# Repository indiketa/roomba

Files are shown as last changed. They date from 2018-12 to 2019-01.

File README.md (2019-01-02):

# roomba
Fa uns mesos que tenim una persona que vé a casa i ens ajuda amb les feines... n'estem molt contents però darrerament sospitem que s'hi està molt menys temps del que hem pactat. Vé quan som fora i no tenim forma de saber quan de temps s'hi està... Sempre havia volgut fer alguna cosa amb arduino: ara n'he tingut l'excusa.

Aquest projecte és una xorrada: Si busques grans desenvolupaments o descobriments t'has equivocat de repositori (i d'usuari)! 
Això és un simple divertimento.

Com que tampoc volía complicar-me la vida (i arriscar-me a fer alguna cosa que no funcionés), vaig decidir muntar el projecte envers a una resistencia LDR: Un tipus de resistència que varia en funció de la llum que hi ha a l'entorn. La idea és situar això a prop de l'entrada, cada vegada que s'obri la porta del carrer la llum variarà de forma notòria, ho detectarem i ens ho guardarem en un registre de text.

Per controlar això hem fet servir una arduino petita xina que hem [trobat](https://www.amazon.es/dp/B01M7ZB2B4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) a l'amazon!

Després d'estar-ho mirant m'adono que l'arduino no té RTC (real time clock) i que de poc ens servrà si no podem saber l'hora, per aquest motiu, vaig comprar també un mòdul RTC que em permeti saber l'hora actual: vaig comprar [aquest](https://www.amazon.es/WINGONEER-DS3231-AT24C32-precisi%C3%B3n-Arduino/dp/B01H5NAFUY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), com que no en sóc cap expert... simplement et diré que dona la hora i la data correctament: Potser la llibreria per tractar-ho es menja molta memòria, rellegint-la per sobre hi ha molt de codi que es podria eliminar i en aquest projecte tot continuaria funcionant.

Ara que ja sabem mesurar la llum i sabem l'hora que és... falta un lloc on desar-ho- com que ho volia tenir ràpid, en comptes d'enviar coses per wifi i haver de tenir algun servei escoltant en alguna banda vaig decidir gravar-ho en una SD local (en plan datalogger). Per aquest motiu vaig afegir-hi un microSD Adapter per aduino... [aquest](https://www.ebay.es/i/272536699694?chn=ps)

Ara sí, ja ho tenim tot, dissenyem el circuit amb l'eagle:

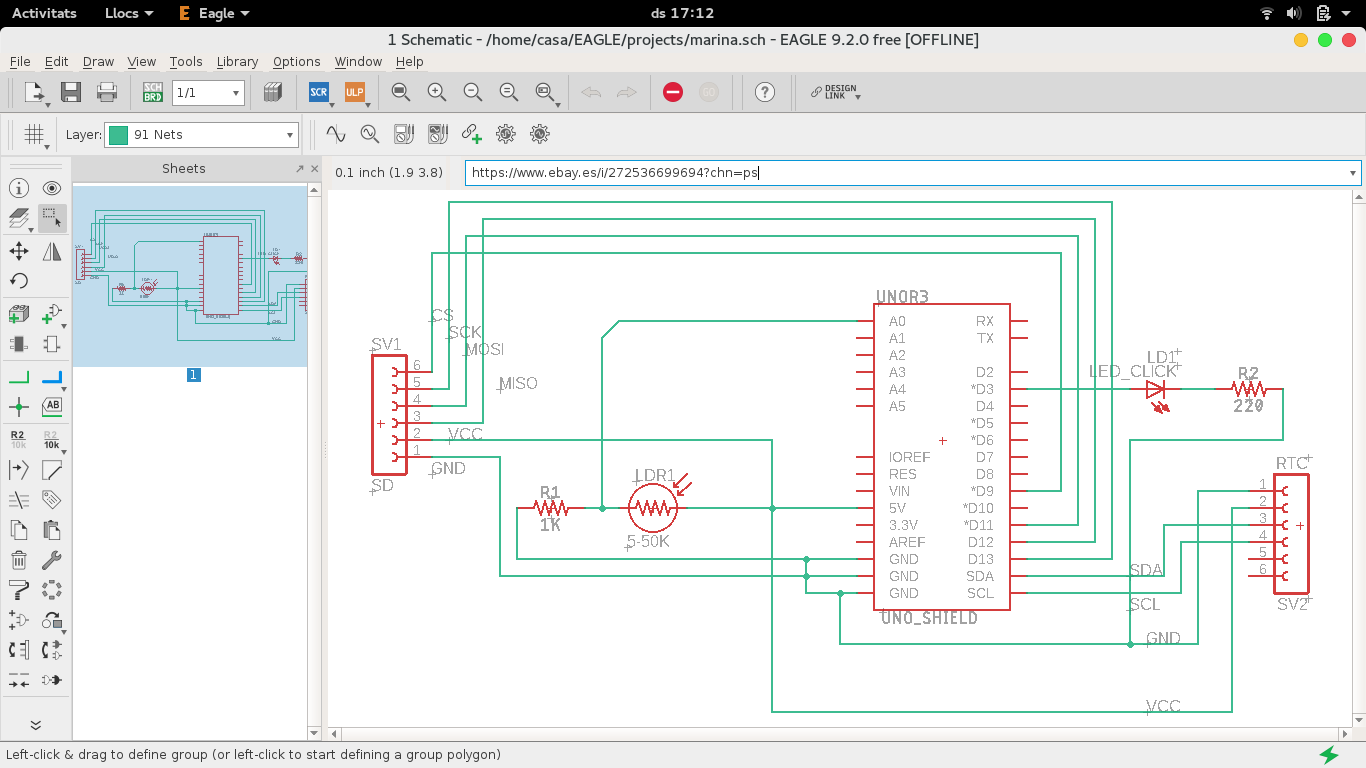
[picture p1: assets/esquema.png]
esquema Esquema


Primer vaig provar-ho tot en una protoboard i va funcionar, però el manyoc de cables per no fer res era considerable. Total que vaig decidir fer-me la placa amb l'EAGLE i fer-la imprimir per internet.La vaig imprimir a https://www.seeedstudio.io:

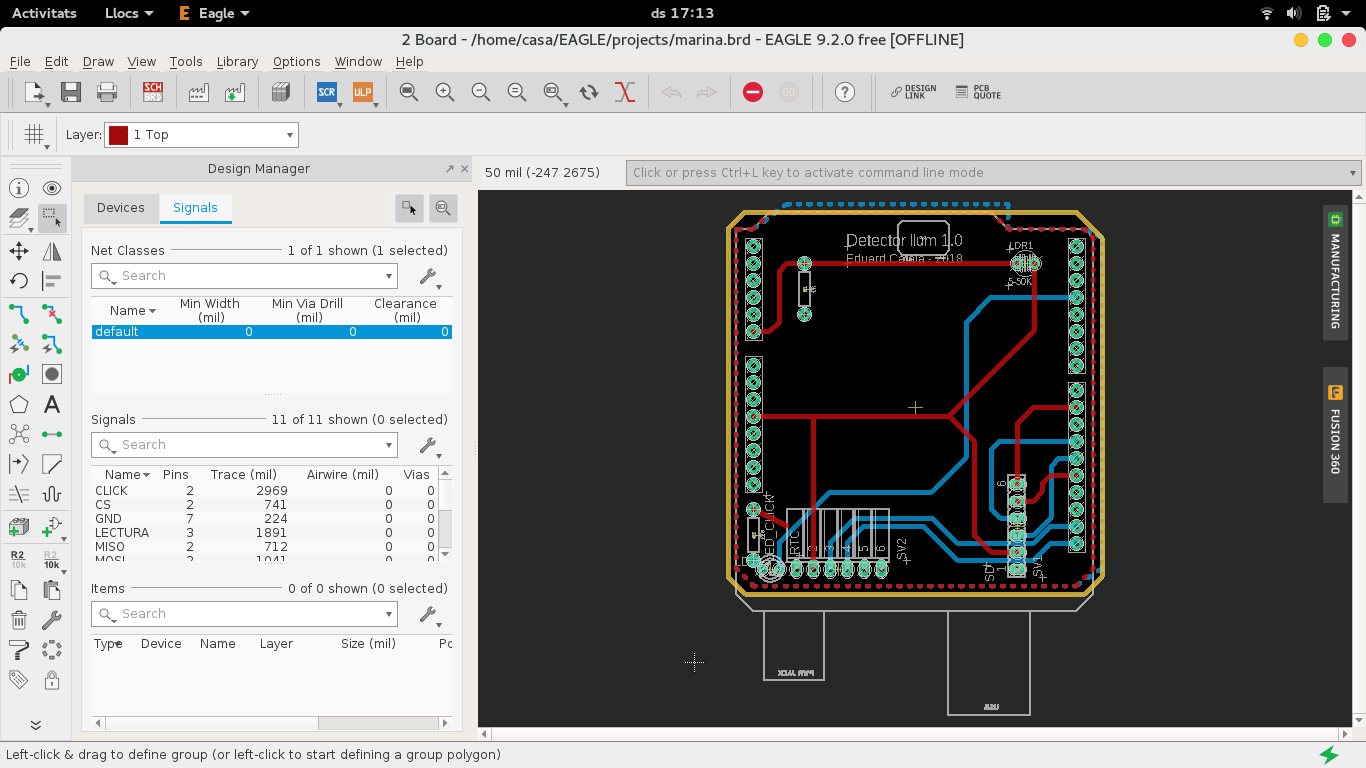
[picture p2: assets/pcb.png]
esquema2 Esquema2

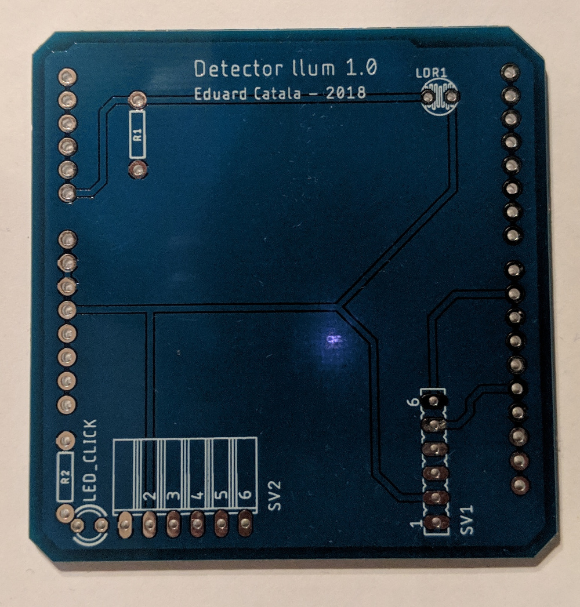
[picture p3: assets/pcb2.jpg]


No és el millor disseny ho sé, el proper invent el farem millor. 

I bàsicament així es com va quedar tot muntat:

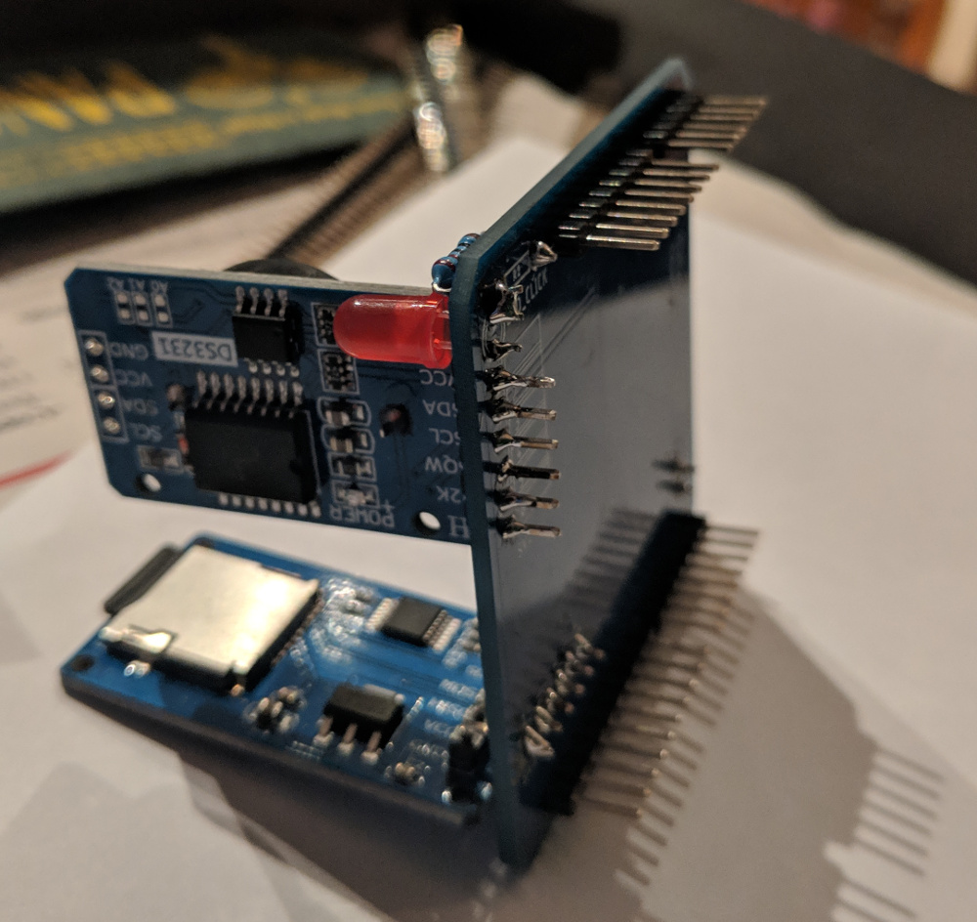
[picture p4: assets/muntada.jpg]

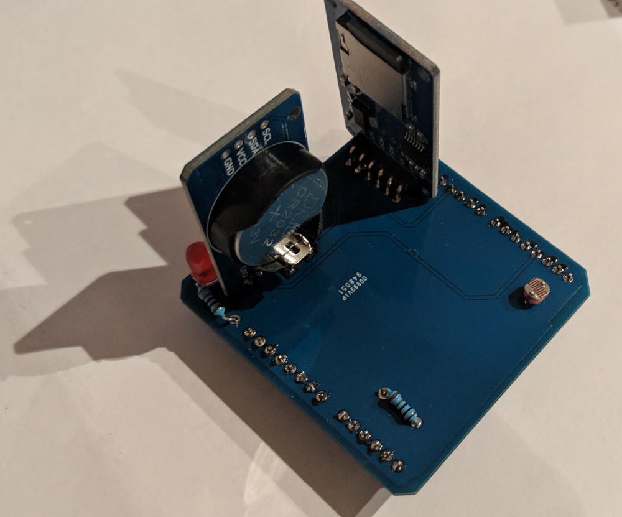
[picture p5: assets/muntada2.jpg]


I acoplat a la arduino uno:

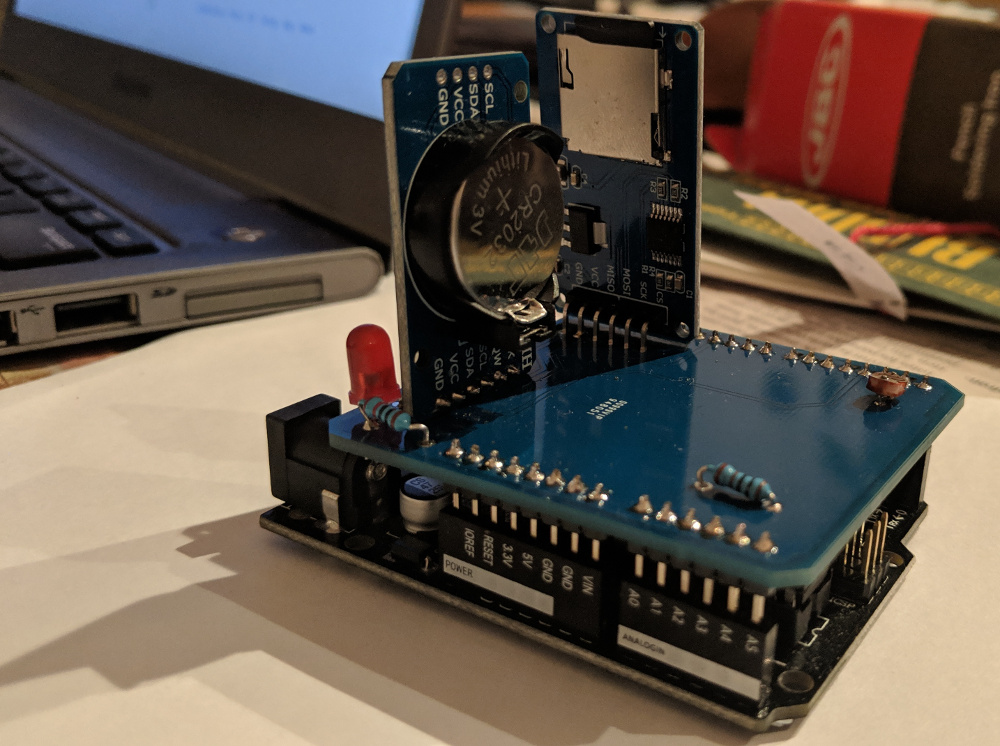
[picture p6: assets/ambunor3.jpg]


Com veieu, al fi i al cap, controlar les hores era el menys important ;)
El cost final del projecte van ser 10€ per l'arduino, 3€ per l'RTC, 3€ per la controladora SD, 5€ per la placa (mínim 5 copies, me'n sobren 4 si algú les vol), i la resistencia LDR no ho sé: cèntims d'euro.

I vet aquí un gat i vet aquí un gos, que aquest compte ja s'ha fos.

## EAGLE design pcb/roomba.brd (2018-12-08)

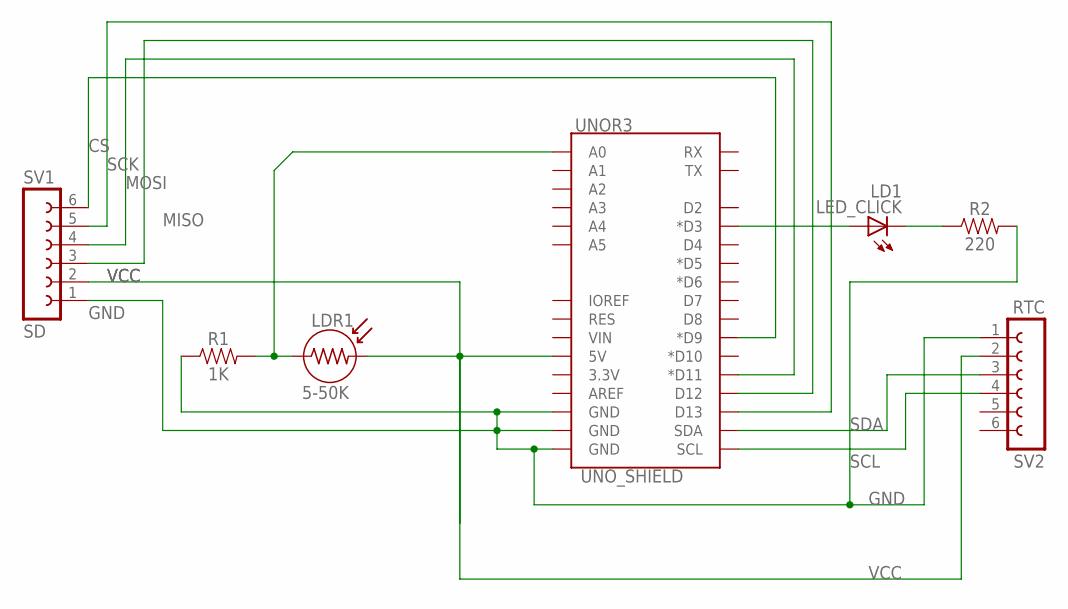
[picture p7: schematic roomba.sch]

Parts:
LDR1: 5-50K; LDR
LED_CLICK: LD1; LED3MM
R1: 1K; AXIAL-0.3
R2: 220; AXIAL-0.3
SV1: SD; FE06
SV2: RTC; FE06W
UNOR3: UNO_SHIELD; UNO_R3_SHIELD_NOLABELS

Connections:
CLICK: LED_CLICK.A, UNOR3.D3 (*D3)
CS: SV1.6, UNOR3.D9 (*D9)
GND: R1.P$1 (1), R2.P$2 (2), SV1.1, SV2.1, UNOR3.GND@0 (GND), UNOR3.GND@1 (GND), UNOR3.GND@2 (GND)
LECTURA: LDR1.1, R1.P$2 (2), UNOR3.A0
MISO: SV1.3, UNOR3.D12
MOSI: SV1.4, UNOR3.D11 (*D11)
RCLICK: LED_CLICK.K (C), R2.P$1 (1)
SCK: SV1.5, UNOR3.D13
SCL: SV2.4, UNOR3.SCL
SDA: SV2.3, UNOR3.SDA
VCC: LDR1.2, SV1.2, SV2.2, UNOR3.5V

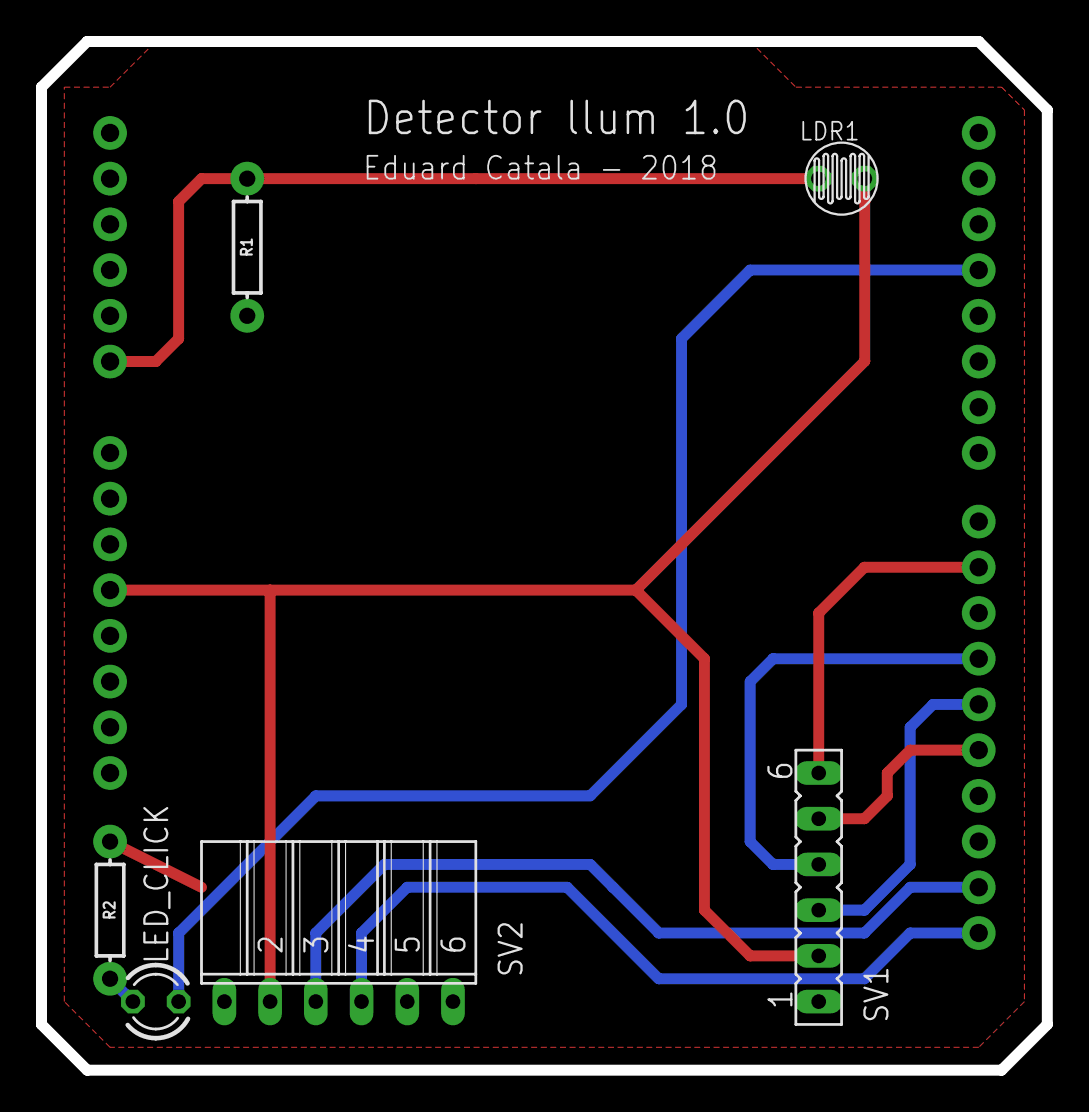
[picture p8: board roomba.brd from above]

Board: 2 copper layers, 55.9 x 57.2 mm, 7 parts (1 on the bottom side), 11 nets.

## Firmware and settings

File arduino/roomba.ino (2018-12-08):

#include <Wire.h>
#include <string.h>
#include <SD.h>
#include "RTClib.h"

#define SD_CS 9
//#define DEBUG 1
#define MIDA_BUFFER 128
#define DESVIACIO_ACTIVA 0.33
#define LED_PWM 3

RTC_DS3231 rtc;
bool disparat = false;
bool estable = false;
unsigned char buffer[MIDA_BUFFER];
unsigned char punter;
unsigned char mitjana;
unsigned char valor;
int suma;

void serial(const char *dades) {
#ifdef DEBUG
  Serial.println(dades);
#endif
}

void serial(const char *dades, int valor) {
#ifdef DEBUG
  Serial.print(dades);
  Serial.println(valor, DEC);
#endif
}


void inicialitzaMitjana() {
  memset(buffer, 0, sizeof buffer);
  punter = 0;
  estable = false;
}

char comprovaValor(int sensor) {
  valor = (char)(sensor >> 2); // El maxim és 1024, treiem 2 bits: 512, 256 -> Ja ens cap en un char.
  char disparat = 'N'; 
  serial("valor=", valor);
  suma -= buffer[punter];
  buffer[punter] = valor;  
  suma += valor;
  punter++;
  punter = punter % MIDA_BUFFER;

  if (!estable && punter == 0) { // Ja tenim el buffer ple, a partir d'ara ja s'hi val disparar-se
    estable = true;
    suma = 0;
    for (int i = 0; i < MIDA_BUFFER; i++) {
      suma = suma + buffer[i];
    }
  }

  if (estable) {
    mitjana = (suma / MIDA_BUFFER);

    if (valor >= mitjana * (1 + DESVIACIO_ACTIVA)) {
      disparat = 'C';
    } else if ( valor <= mitjana * (1 - DESVIACIO_ACTIVA)) {
      disparat = 'F';
    }

  }

  return disparat;
}

char* f00(char* dades) {
  if (strlen(dades) == 1) {  // Formata amb zero per davant (quina pijeria, tu!)
    dades[1] = dades[0]; 
    dades[0] = '0';
    dades[2] = 0;
  }
  return dades;
}

void formatar(DateTime date, char* str)
{
  char aux[5];
  itoa(date.day(), aux, 10);
  strcat(str, f00(aux));
  strcat(str, "/");
  itoa(date.month(), aux, 10);
  strcat(str, f00(aux));
  strcat(str, "/");
  itoa(date.year(), aux, 10);
  strcat(str, aux);

  strcat(str, " ");
  itoa(date.hour(), aux, 10);
  strcat(str, aux);
  strcat(str, ":");
  itoa(date.minute(), aux, 10);
  strcat(str, f00(aux));
  strcat(str, ":");
  itoa(date.second(), aux, 10);
  strcat(str, f00(aux));
  strcat(str, " MITJANA: ");
  itoa(mitjana, aux, 10);
  strcat(str, aux);
  strcat(str, " VALOR: ");
  itoa(valor,aux, 10);
  strcat(str, aux);
}

void ledFlash(){ // Fem visible que ens hem disparat.
  
 for (int voltes = 1; voltes < 6; voltes++) {
  digitalWrite(LED_PWM, HIGH);   
  delay(100);                    
  digitalWrite(LED_PWM, LOW);    
  delay(100);                      
 }
  
}

void setup() {
  
  // Led de sortida
  pinMode(LED_PWM, OUTPUT);
  digitalWrite(LED_PWM, HIGH); // L'encenem abans de fer setup i l'apaguem quan acabem així sabem si estem al bucle o al setup en cas de problemes.
  
#ifdef DEBUG
  // debug
  Serial.begin(9600);
#endif

  // rellotge
  while (!rtc.begin()) {
    serial("No trobo el rellotge");
    delay(1000);
  }

  // Si el rellotge ha perdut la corrent
  if (rtc.lostPower()) {
    // Establim la hora que s'ha compilat aquest programa
    rtc.adjust(DateTime(F(__DATE__), F(__TIME__)));

    // Posar-la a pel:
    // rtc.adjust(DateTime(2016, 1, 21, 3, 0, 0));
  }

  // Targeta SD
  while (!SD.begin(SD_CS)) {
    serial("SD: Problema, no targeta o fallo");
    delay(1000);
  }

  // inicialitzar buffer
  inicialitzaMitjana();

  // Indiquem que ja està a punt
  delay(500); // Que tinguem temps de veure que passa pel setup
  digitalWrite(LED_PWM, LOW);
}

void loop() {
  int lecturaSensor = analogRead(A0);

  char disparat = comprovaValor(lecturaSensor);
  bool gravar = false;
  char desc[7];

  desc[0] = 0;

  if (disparat == 'C') {
    strcat(desc, " CLAR");
    gravar = true;
  } else if (disparat == 'F') {
    strcat(desc, " FOSC");
    gravar = true;
  }

  if (gravar) {
    inicialitzaMitjana();
    char cadena[64];
    cadena[0] = 0;
    formatar(rtc.now(), cadena);
    strcat(cadena, desc);
    serial(cadena);
    File fitxer = SD.open("log.txt", FILE_WRITE);
    if (fitxer) {
      fitxer.println(cadena);
      fitxer.close();
    }
    ledFlash();
  }

  delay(100);
}

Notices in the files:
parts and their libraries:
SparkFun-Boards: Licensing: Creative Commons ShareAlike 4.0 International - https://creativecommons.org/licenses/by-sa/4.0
